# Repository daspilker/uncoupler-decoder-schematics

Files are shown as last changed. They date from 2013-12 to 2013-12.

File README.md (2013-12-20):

Uncoupler Decoder
=================

This repository contains schematics and PCB design files for an decoder for the Märklin Digital system. The decoder has only one output and is well suited for uncoupler tracks.

These files have been created with the [EAGLE](http://www.cadsoftusa.com/) PCB software.

The PCB design meets the specifications of [OSH Park](http://oshpark.com/) community PCB order.

Bill Of Materials
-----------------

* **B1** RECT BRIDGE GPP 50V 1A DFS (DigiKey 641-1344-5-ND)
* **S1** SWITCH TAPE SEAL 9 POS SMD (DigiKey CT2199LPST-ND)
* **IC1** IC MCU AVR 2K FLASH 20SOIC (DigiKey ATTINY2313-20SU-ND)
* **IC2** IC VREG 100MA 5V SOT-89 (DigiKey MC78L05ACHXCT-ND)
* **C1** CAPACITOR TANT .10UF 35V 10% SMD (DigiKey 399-3676-1-ND)
* **C2** CAPACITOR TANT .33UF 35V 10% SMD (DigiKey 399-3693-1-ND)
* **C3** CAPACITOR TANT 10UF 25V 10% SMD (DigiKey 399-3734-1-ND)
* **D3** DIODE 75V 150MA SOD323F (DigiKey 1N4148WSFSCT-ND)
* **T1** TRANS NPN DARL 120V SOT23F-3 (DigiKey ZXTN04120HFFCT-ND)
* **R1** RES 270K OHM 1/8W 1% 0805 SMD (DigiKey RHM270KCCT-ND)
* **R2** RES 10.0K OHM 1/8W 1% 0805 SMD (DigiKey RHM10.0KCCT-ND)
* **R3** RES 4.70K OHM 1/8W 1% 0805 SMD (DigiKey RHM4.70KCCT-ND)

License
-------

Copyright 2012 Daniel A. Spilker

Licensed under the Apache License, Version 2.0 (the "License");
you may not use this file except in compliance with the License.
You may obtain a copy of the License at

    http://www.apache.org/licenses/LICENSE-2.0

Unless required by applicable law or agreed to in writing, software
distributed under the License is distributed on an "AS IS" BASIS,
WITHOUT WARRANTIES OR CONDITIONS OF ANY KIND, either express or implied.
See the License for the specific language governing permissions and
limitations under the License.

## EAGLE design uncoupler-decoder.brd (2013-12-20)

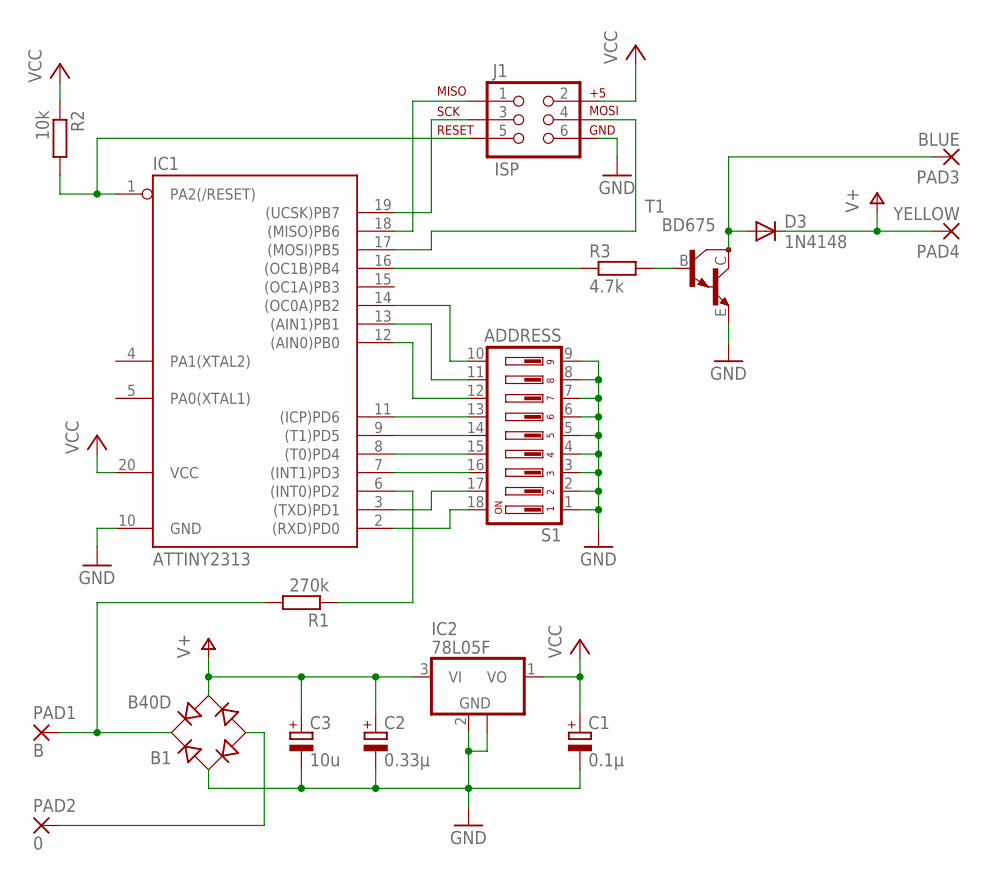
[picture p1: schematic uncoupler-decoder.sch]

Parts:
B1: B40D; B40S
C1: 0.1µ; A/3216-18R
C2: 0.33µ; A/3216-18R
C3: 10u; CT6032
D3: 1N4148; SOD323-R
IC1: ATTINY2313; SO20L$
IC2: 78L05F; SOT89
J1: ISP; ISP-ADAPTER-SMD
PAD1: B; SMD1,27-2,54
PAD2: 0; SMD1,27-2,54
PAD3: BLUE; SMD1,27-2,54
PAD4: YELLOW; SMD1,27-2,54
R1: 270k; R0805
R2: 10k; R0805
R3: 4.7k; R0805
S1: ADDRESS; CTS-219-09
T1: BD675; SOT23-BEC

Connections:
B: B1.+, PAD1.1, R1.2
GND: B1.AC1, C1.-, C2.-, C3.-, IC1.10 (GND), IC2.2 (GND), IC2.2@1 (GND), J1.6, S1.1, S1.2, S1.3, S1.4, S1.5, S1.6, S1.7, S1.8, S1.9, T1.E
unnamed: R3.2, T1.B
unnamed: IC1.11 ((ICP)PD6), S1.13
unnamed: IC1.9 ((T1)PD5), S1.14
unnamed: IC1.1 (PA2(/RESET)), J1.5, R2.2
unnamed: IC1.8 ((T0)PD4), S1.15
unnamed: IC1.7 ((INT1)PD3), S1.16
unnamed: B1.-, PAD2.1
unnamed: IC1.16 ((OC1B)PB4), R3.1
unnamed: D3.A, PAD3.1, T1.C
unnamed: IC1.18 ((MISO)PB6), J1.1
unnamed: IC1.3 ((TXD)PD1), S1.17
unnamed: IC1.19 ((UCSK)PB7), J1.3
unnamed: IC1.17 ((MOSI)PB5), J1.4
unnamed: IC1.14 ((OC0A)PB2), S1.10
unnamed: IC1.13 ((AIN1)PB1), S1.11
unnamed: IC1.12 ((AIN0)PB0), S1.12
unnamed: IC1.2 ((RXD)PD0), S1.18
unnamed: IC1.6 ((INT0)PD2), R1.1
V+: B1.AC2, C2.+, C3.+, D3.C, IC2.3 (VI), PAD4.1
VCC: C1.+, IC1.20 (VCC), IC2.1 (VO), J1.2, R2.1

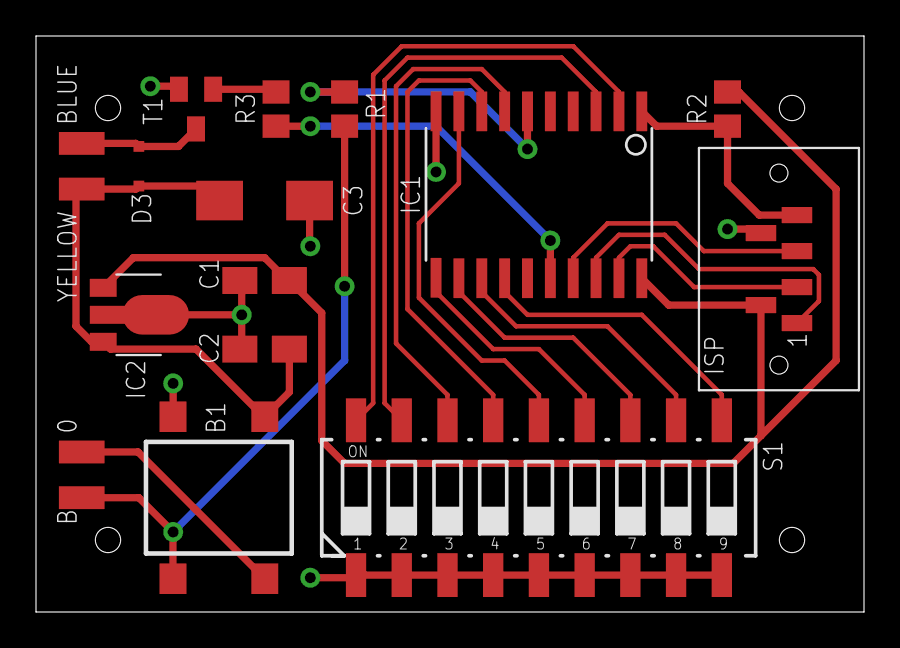
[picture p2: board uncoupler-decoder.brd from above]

Board: 2 copper layers, 46.0 x 32.0 mm, 17 parts (0 on the bottom side), 22 nets.

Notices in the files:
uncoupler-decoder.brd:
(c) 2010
